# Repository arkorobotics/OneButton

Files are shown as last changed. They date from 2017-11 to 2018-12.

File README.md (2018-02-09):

# OneButton

The OneButton is a programmable single-key USB Keyboard with RGB LED's.

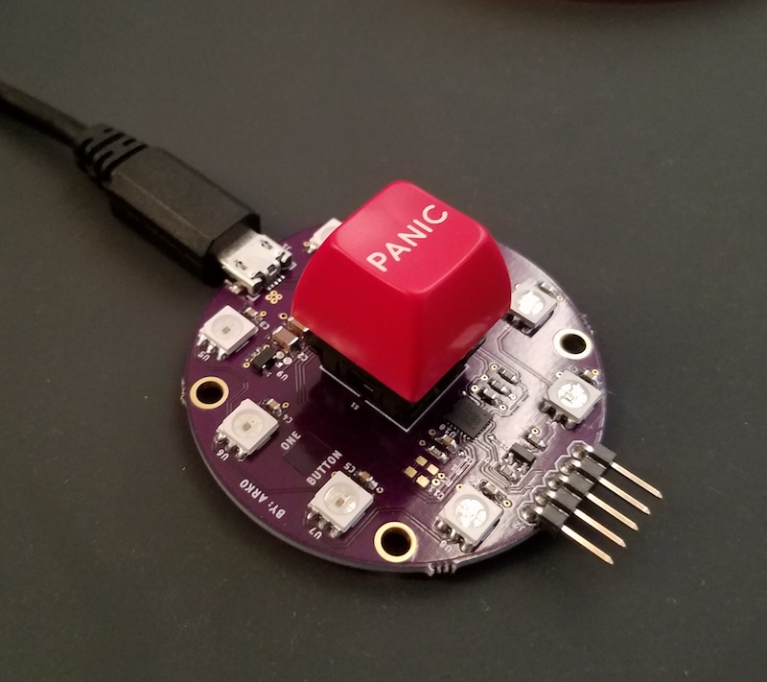
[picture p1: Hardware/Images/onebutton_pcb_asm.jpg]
onebutton Fully assmbled OneButton PCB


The OneButton serves no single purpose, but rather is designed to be programmed for multiple uses.

Possible Applications: 
- Generate pre-scripted USB keystrokes (included in the example code)
- Serve as a "Soft" E-STOP button with color LED's to indicate state
- Interface with a desktop API to perform other actions (i.e. - Indiciate a new Tweet notification by turning LED's Blue. Pressing the key opens Twitter.)
- The possiblities are not endless!

The OneButton includes six programmable RGB LED's because everyone loves blinky lights! <br>
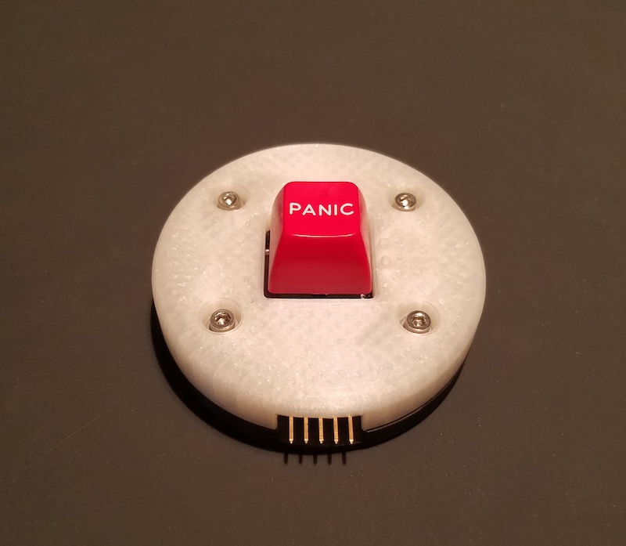
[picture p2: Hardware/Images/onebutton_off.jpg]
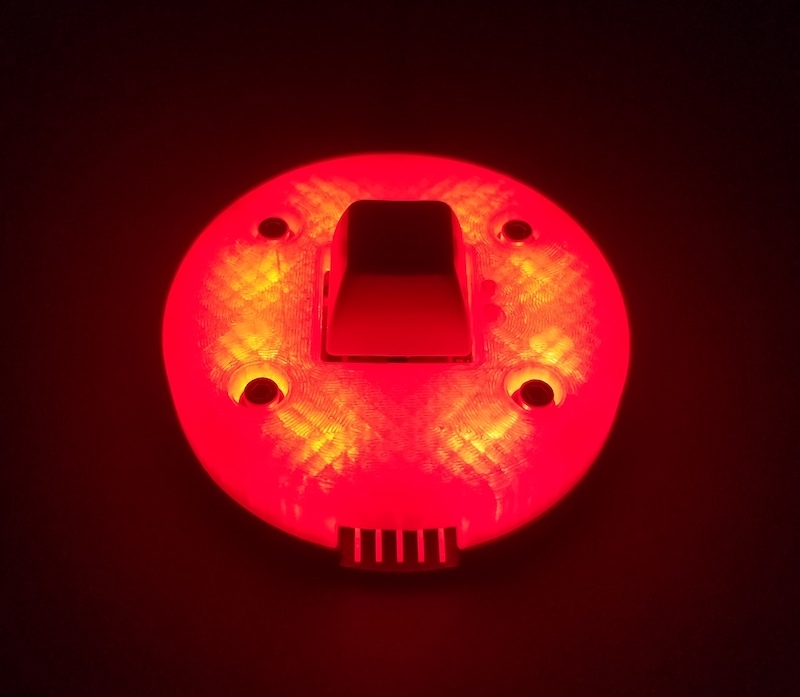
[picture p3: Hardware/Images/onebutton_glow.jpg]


...and easter eggs!<br>
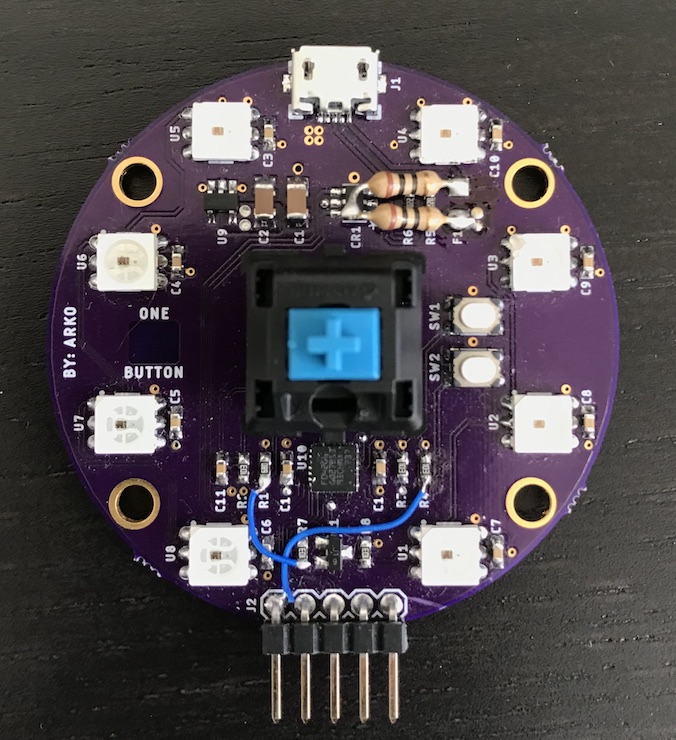
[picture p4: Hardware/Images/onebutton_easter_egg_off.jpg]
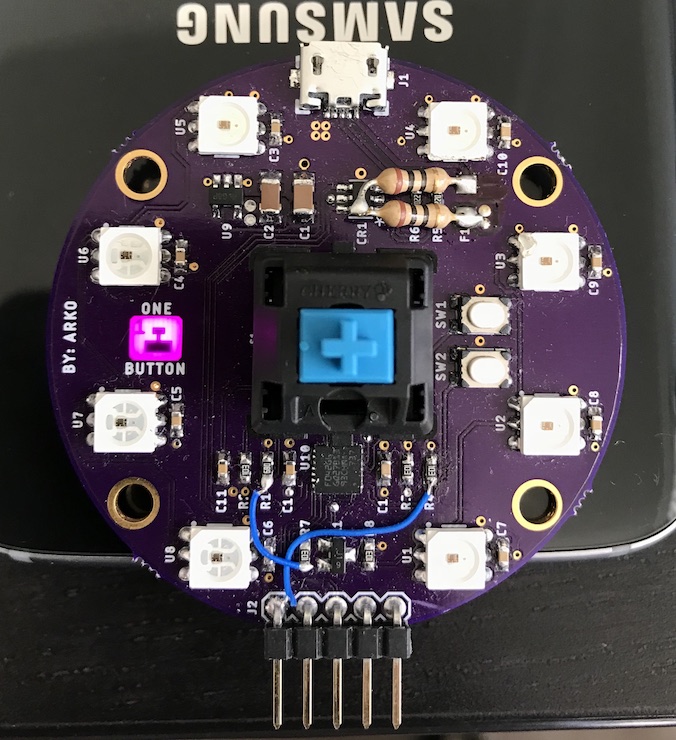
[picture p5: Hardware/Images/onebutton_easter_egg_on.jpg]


Included in this GitHub:
- Firmware: Example code written in C++ and Rust 
- Hardware: Schematic, Board, Gerber, and 3D printable enclosure CAD files

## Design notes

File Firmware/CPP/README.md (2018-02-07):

# OneButton - C++ Firmware

## Installation

1. Download and install the arm-none-eabi gcc toolchain

	https://developer.arm.com/open-source/gnu-toolchain/gnu-rm/downloads
	We recommend installing the precompiled binaries to '/usr/local'. 
	Add the bin folders (/bin & /arm-none-eabi/bin) to your environments variable 'PATH'.

2. Install STLink Tool

	https://github.com/texane/stlink

3. Install OpenOCD

	`$ brew update openocd`

4. Instal GDB Dashboard

	https://github.com/cyrus-and/gdb-dashboard

5. Install scons

	`$ brew install scons`

## Build

1. Build source using scons
	
	Optimized:

	`$ scons mode=fast mcu=f042 hsi=48000000`

	Debug:

	`$ scons mode=debug mcu=f042 hsi=48000000`

## Flash Device

1. Flash device with optimized binary using st-flash

	`$ st-flash --format ihex write src/build/fast-f042-48000000i/onebutton.hex`

## Debug using GDB

1. Build debug binary

	`$ scons mode=debug mcu=f042 hsi=48000000`

2. Open two terminal screens

3. Terminal 1: St-Util

	`$ st-util -m`

4. Terminal 2: GDB Session

	`$ arm-none-eabi-gdb src/build/debug-f042-48000000i/onebutton.elf`

	`(gdb) target extended-remote localhost:4242`

	`(gdb) load` 

	If it fails to flash, reset the device and try again.

	Reset the device manually (TODO: Fix the load/reset procedure to reset automatically after load. Uncertain if it's SW or HW issue.)

	`(gdb) continue`

## Debug using GDB Py with GDB Dashboard

1. Build debug binary

	`$ scons mode=debug mcu=f042 hsi=48000000`

2. Open three terminal screens

3. Terminal 1: St-Util

	`$ st-util -m`

4. Terminal 2: GDB Dashboard Output

	`$ tty` 

	Note the tty session. We will use this in the following steps. (i.e. "/dev/ttys001")

5. Terminal 3: GDB Py Session

	`$ cd OneButton/Firmware/CPP`

	`$ arm-none-eabi-gdb-py src/build/debug-f042-48000000i/onebutton.elf`

	`>>> dashboard -output /dev/ttys001`

	`>>> target extended-remote localhost:4242`

	`>>> load`

	If it fails to flash, reset the device and try again.

	Reset the device manually

	`>>> continue`

	`>>> continue`

6. To load new firmware after a new build

	`>>> load`

	Reset the device manually

	`>>> continue`

	`>>> continue`

7. To recover after a segfault

	`>>> kill`

	`>>> load`

	`>>> target extended-remote localhost:4242`

	`>>> continue`

	`>>> continue`

8. To exit gracefully

	`>>> kill`

	`>>> quit`

## Check for USB HID Devices

`$ system_profiler SPUSBDataType`

## Credits

Base library:  https://github.com/andysworkshop/stm32plus

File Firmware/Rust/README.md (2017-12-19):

# OneButton - Rust Firmware

## Installation

1. Download and install the arm-none-eabi gcc toolchain

https://developer.arm.com/open-source/gnu-toolchain/gnu-rm/downloads
We recommend installing the precompiled binaries to '/usr/local'. 
Add the bin folders (/bin & /arm-none-eabi/bin) to your environments variable 'PATH'.

2. Install STLink Tool

https://github.com/texane/stlink

3. Install OpenOCD

`$ brew update openocd`

4. Install Rust

`$ curl https://sh.rustup.rs -sSf | sh`

5. Install xargo

`$ cargo install xargo`

6. Set toolchain to default nightly build

`$rustup default nightly`

7. Install Rust Sources

`$ rustup component add rust-src`

## Build

1. Build command

`$ xargo build --release`

## Flash

1. Generate Hex File
`arm-none-eabi-objcopy -O ihex target/thumbv6m-none-eabi/release/onebutton onebutton.ihex`

2. Flash command
`st-flash --format ihex write onebutton.ihex`

## Credits

Base toolchain:  https://github.com/therealprof/stm32f042

USB HID Library: https://github.com/Determinant/bluepill-momo2

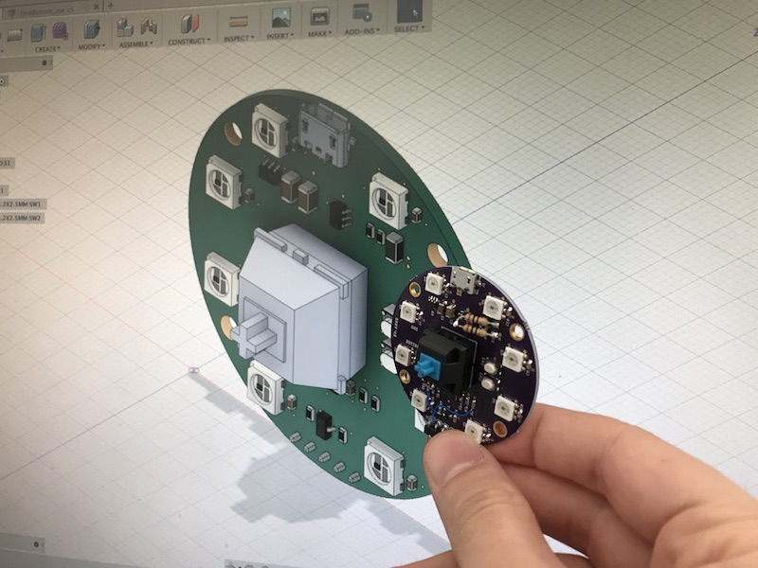
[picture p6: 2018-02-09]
Hardware/Images/onebutton_cad_vs_irl.jpg

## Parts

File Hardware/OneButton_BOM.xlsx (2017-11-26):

Qty | Value | Device | Package | Parts | Description | MPN | Cost | Link
1 |  | CONN_05 | 1X05 | J2 | Multi connection point. Often used as Generic Header-pin footprint for 0.1 inch spaced/style header connections | 61300511121 | 0.25 | https://www.digikey.com/product-detail/en/wurth-electronics-inc/61300511121/732-5318-ND/4846831
1 |  | PTCFUSE-1206 | R1206 | F1 | PTC fuses, resettable thermistors | 0ZCG0075FF2C | 0.13 | https://www.digikey.com/product-detail/en/bel-fuse-inc/0ZCG0075FF2C/507-1763-1-ND/4156150
1 |  | USB_AB_SMT | USB-AB-MICRO-SMD | J1 | USB Type AB Micro Connector | 10118192-0001LF | 0.46 | https://www.digikey.com/product-detail/en/amphenol-fci/10118192-0001LF/609-4613-1-ND/2785378
10 | 0.1uF | 0.1UFCAP-0603 | CAP-0603 | C3, C4, C5, C6, C7, C8, C9, C10, C14, C15 | 0.1µF ceramic capacitors | C0603C104K8RACTU | 0.029 | https://www.digikey.com/product-detail/en/kemet/C0603C104K8RACTU/399-1095-1-ND/411370
4 | 10k | RESISTORRES-0603 | RESC0603_N | R3, R4, R7, R8 | Generic Resistor Package | RC0603JR-0710KL | 0.044 | https://www.digikey.com/product-detail/en/yageo/RC0603JR-0710KL/311-10KGRCT-ND/729647
1 | 10uF | 10UFCAP-1206 | CAP-1206 | C1 | 10.0µF ceramic capacitors | CL31B106KAHNNNE | 0.26 | https://www.digikey.com/product-detail/en/samsung-electro-mechanics/CL31B106KAHNNNE/1276-1804-1-ND/3889890
2 | 22R | RESISTORRES-0603 | RESC0603_N | R5, R6 | Generic Resistor Package | RC0603JR-0722RL | 0.022 | https://www.digikey.com/product-detail/en/yageo/RC0603JR-0722RL/311-22GRCT-ND/729690
1 | 3.3V | V_REG_AP2112K-3.3V | SOT23-5 | U9 | AP2112 - 600mA CMOS LDO Regulator w/ Enable | AP2112K-3.3TRG1 | 0.48 | https://www.digikey.com/product-detail/en/diodes-incorporated/AP2112K-3.3TRG1/AP2112K-3.3TRG1DICT-ND/4505257
1 | 4.7uF | 4.7UFCAP-1206 | CAP-1206 | C2 | 4.7µF ceramic capacitors | C3216X7R1C475K160AB | 0.27 | https://www.digikey.com/product-detail/en/tdk-corporation/C3216X7R1C475K160AB/445-1385-1-ND/567617
1 | 68R | RESISTORRES-0603 | RESC0603_N | R1 | Generic Resistor Package | RC0603JR-0768RL | 0.1 | https://www.digikey.com/product-detail/en/yageo/RC0603JR-0768RL/311-68GRCT-ND/729768
1 | BSS138W-7-F | SMD-MOSFET-N-CH-50V-200MA-BSS138W-7-F(SOT-23) | SOT-23 | Q1 | SMD-MOSFET-N-CH | BSS138LT1G | 0.29 | https://www.digikey.com/product-detail/en/on-semiconductor/BSS138LT1G/BSS138LT1GOSCT-ND/917858
2 | DHT-4235A | SMD-BUTTON-TOP-DHT-4235A(4P-4.2X3.2MM) | SW4-SMD-4.2X3.2X2.5MM | SW1, SW2 | 311020045 | PTS810 SJK 250 SMTR LFS | 0.56 | https://www.digikey.com/product-detail/en/c-k/PTS810-SJK-250-SMTR-LFS/CKN10503CT-ND/4176675
1 | DNP | CAPACITORCAP-0603 | CAP-0603 | C11 | Generic chip capacitor | - | - | -
1 | DNP | RESISTORRES-0603 | RESC0603_N | R2 | Generic Resistor Package | - | - | -
1 | MOMENTARY-SWITCH-SPST-LED-PTH-CHERRY | MOMENTARY-SWITCH-SPST-LED-PTH-CHERRY | CHERRY-MX-LED | S1 | Momentary Switch (Pushbutton) - SPST - w/ LED | MX1A-E1NW | 0.9 | https://www.digikey.com/product-detail/en/cherry-americas-llc/MX1A-E1NW/CH197-ND/20180
1 | STM32F042GU | STM32F042GU | UFQFPN28 | U10 |  | STM32F042G6U6 | 2.45 | https://www.digikey.com/product-detail/en/stmicroelectronics/STM32F042G6U6/497-17345-ND/5268192
1 | USBLC6-2SC6SOT23-6L-M | USBLC6-2SC6SOT23-6L-M | SOT23-6L-M | CR1 |  | USBLC62SC6 | 0.42 | https://www.digikey.com/product-detail/en/stmicroelectronics/USBLC6-2SC6/497-5235-1-ND/1121688
8 | WS2812 | WS2812";LED-TRICOLOR-5050-IC" |  | U1, U2, U3, U4, U5, U6, U7, U8 | WS2812 RGB LED w/ WS2811 driver | WS2812 | 0.5 | https://www.sparkfun.com/products/11821
 |  |  |  |  |  |  | 7.165

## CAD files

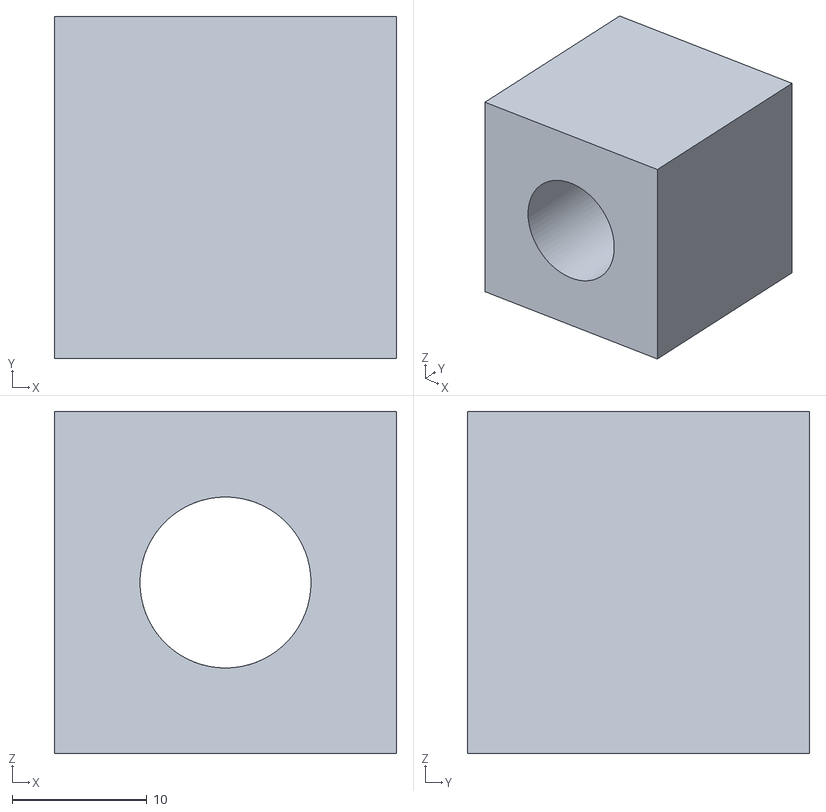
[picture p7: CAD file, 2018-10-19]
Hardware/CAD/Gourgen_Cube.stl
25.4 x 25.4 x 25.4

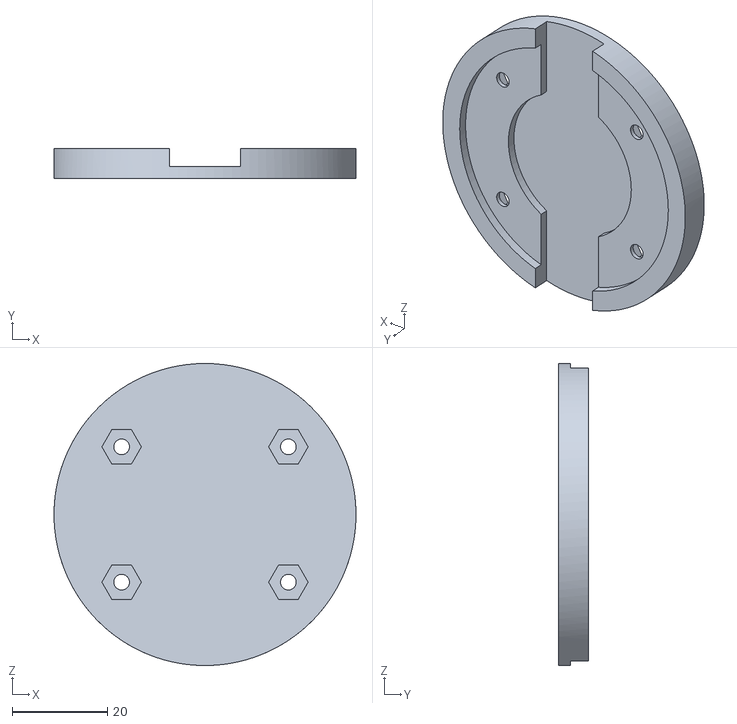
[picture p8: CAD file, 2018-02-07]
Hardware/CAD/OneButtonCase_Bottom v15.stl
63.5 x 6.35 x 63.5

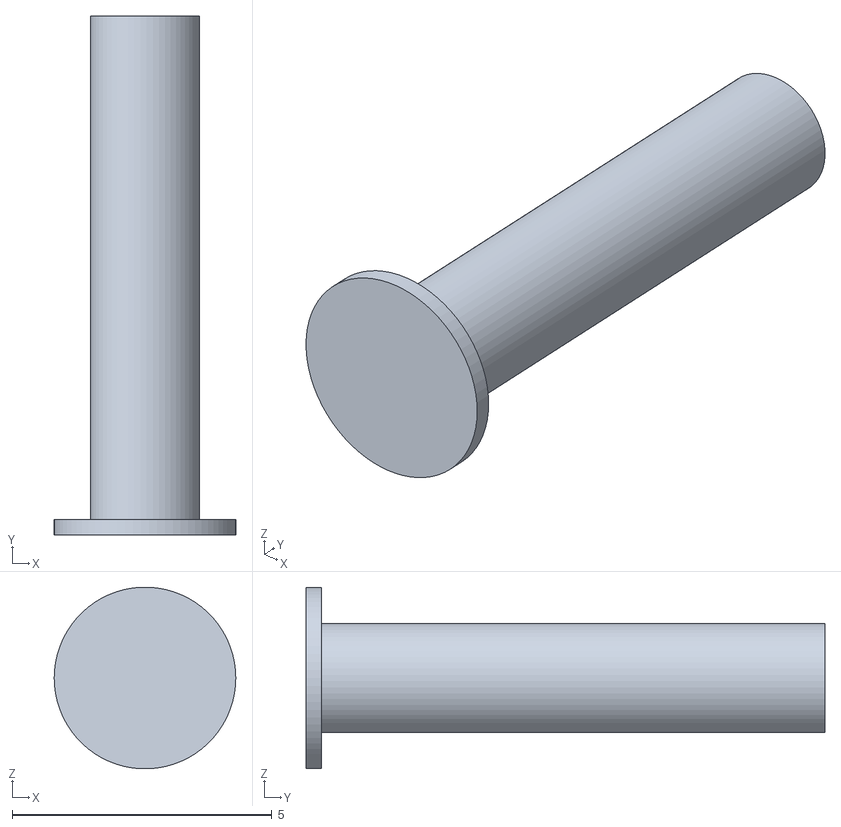
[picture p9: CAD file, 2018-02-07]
Hardware/CAD/OneButton_Reset_Boot_Button_v9.stl
3.50 x 10.0 x 3.50

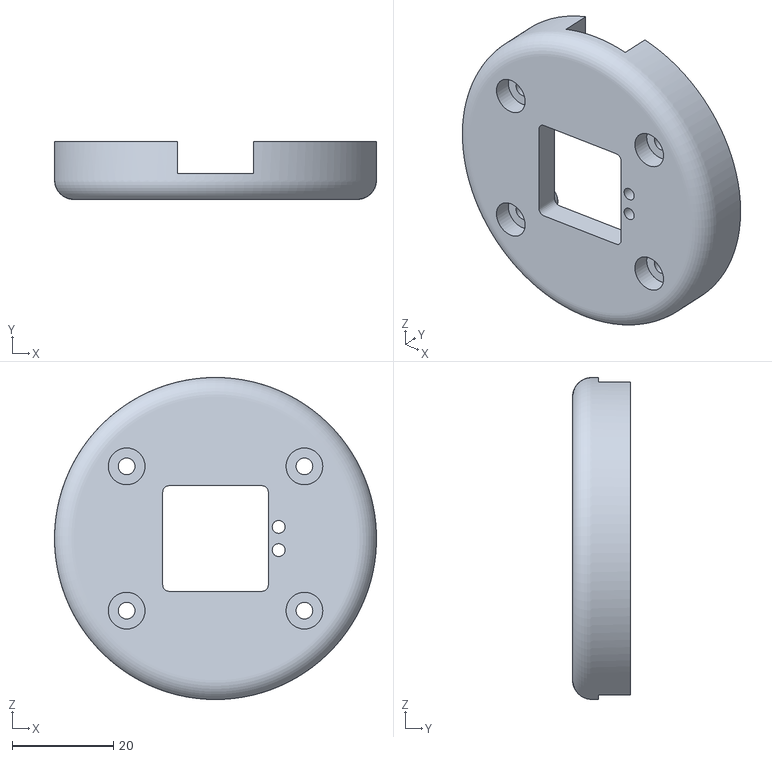
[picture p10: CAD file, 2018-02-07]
Hardware/CAD/OneButtonCase_Top v19.stl
63.5 x 11.4 x 63.5

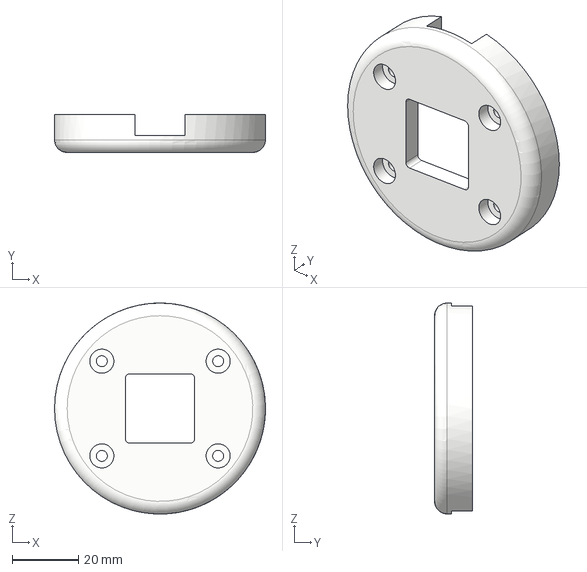
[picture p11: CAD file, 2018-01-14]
Hardware/CAD/OneButtonCaseTop.step
63.5 x 11.4 x 63.5 mm

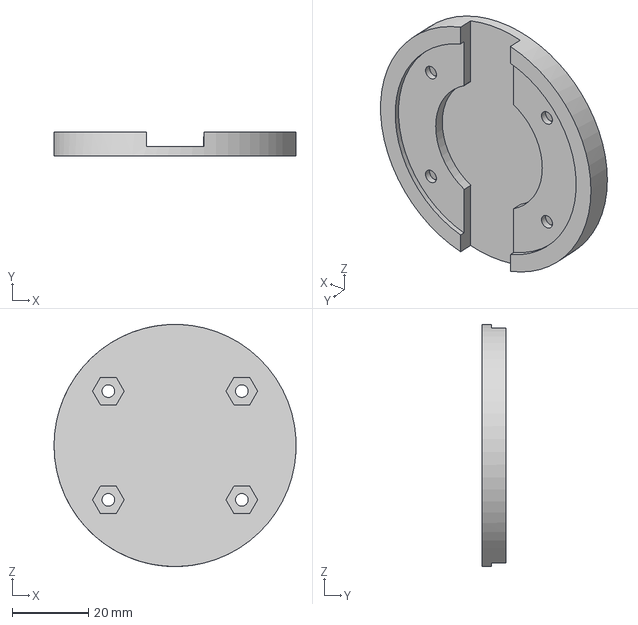
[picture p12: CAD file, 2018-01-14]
Hardware/CAD/OneButtonCaseBottom.step
63.5 x 6.35 x 63.5 mm

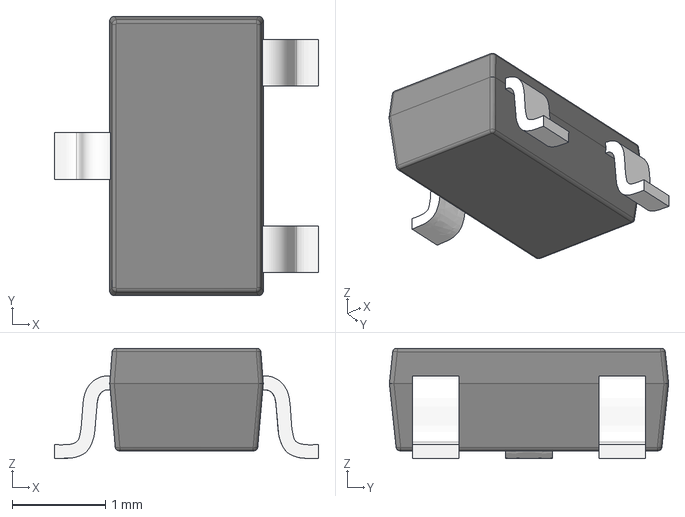
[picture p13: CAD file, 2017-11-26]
Hardware/CAD/SOT23-3.stp
2.84 x 3.00 x 1.18 mm

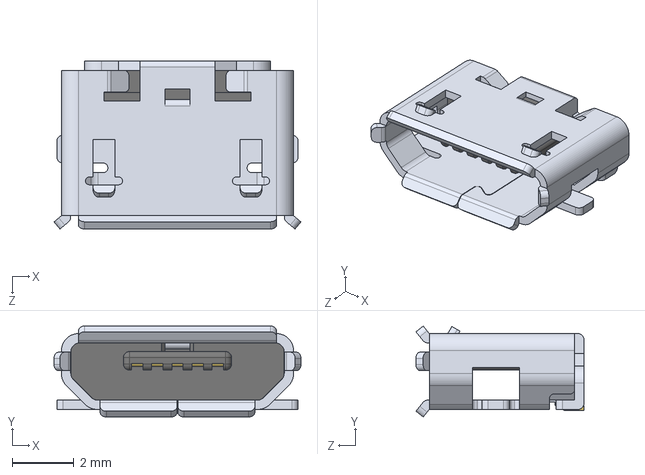
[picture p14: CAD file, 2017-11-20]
Hardware/CAD/USB_Micro.STEP
7.98 x 2.94 x 5.43 mm

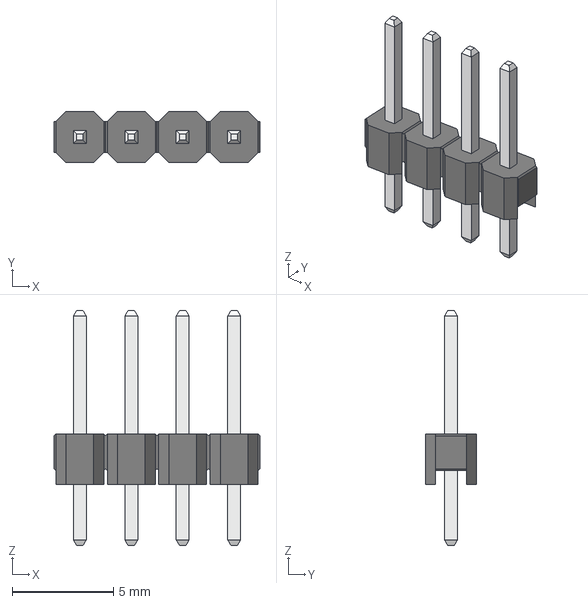
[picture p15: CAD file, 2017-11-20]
Hardware/CAD/DS1021-1x4S61.stp
10.2 x 2.54 x 11.6 mm

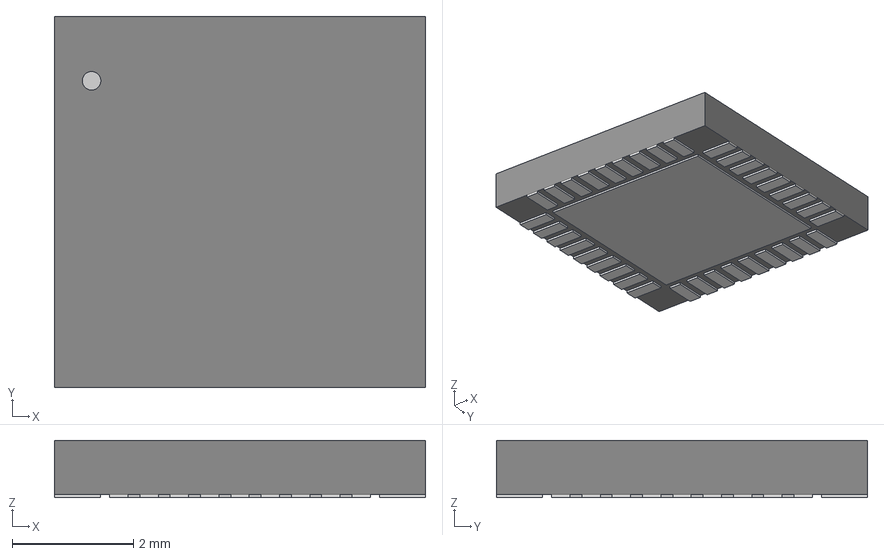
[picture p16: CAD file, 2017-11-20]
Hardware/CAD/VFQFPN-36.step
6.12 x 6.12 x 0.942 mm

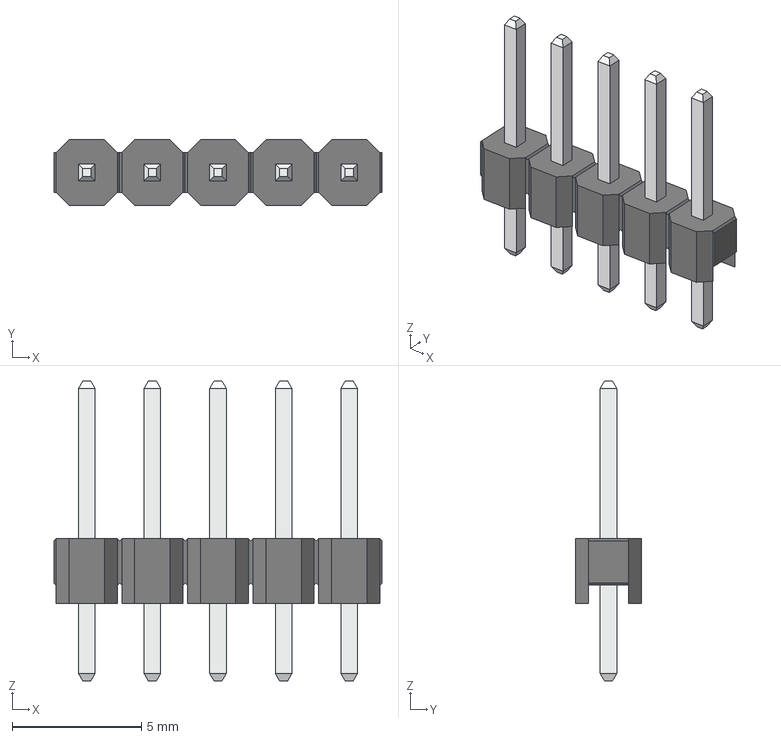
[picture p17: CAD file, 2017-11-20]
Hardware/CAD/DS1021-1x5S61.stp
12.7 x 2.54 x 11.6 mm

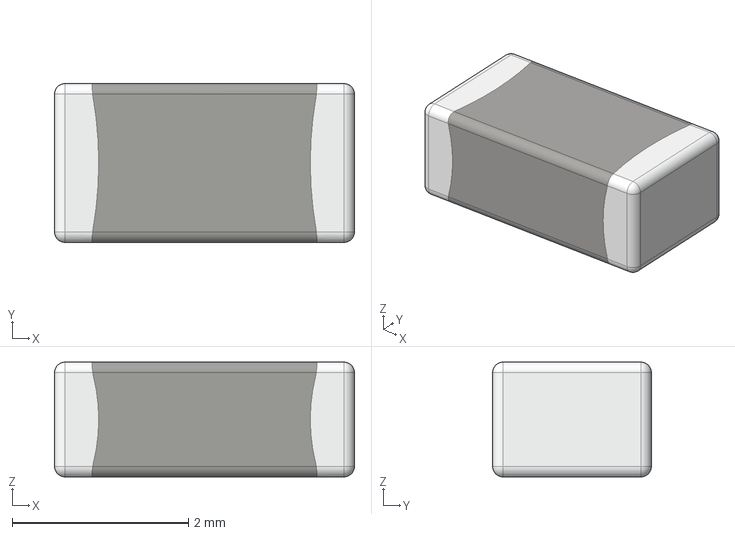
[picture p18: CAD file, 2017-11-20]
Hardware/CAD/NTC-1206-T1.3.stp
3.40 x 1.80 x 1.30 mm

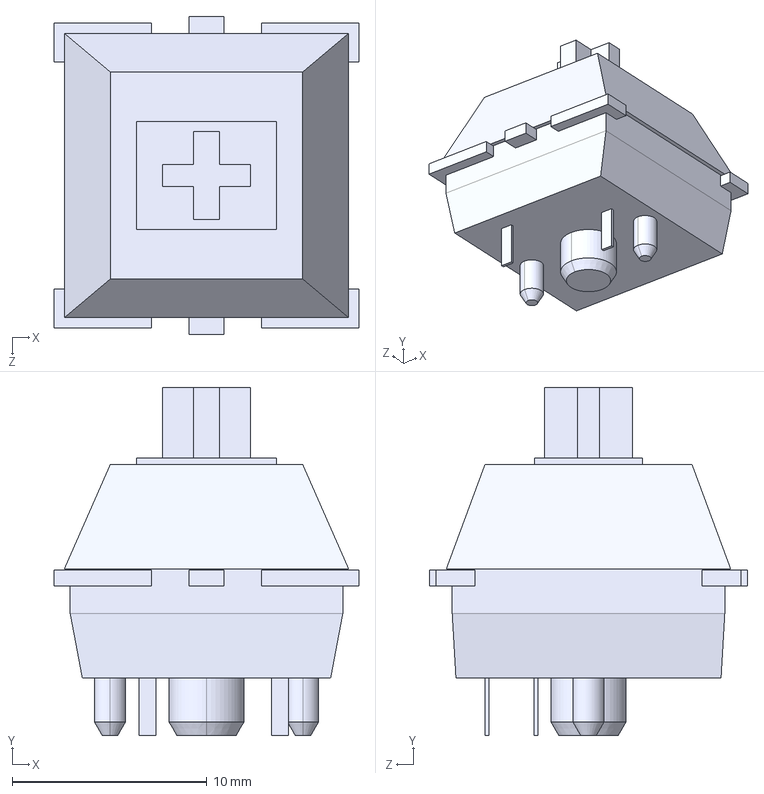
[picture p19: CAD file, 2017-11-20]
Hardware/CAD/MX_Cherry.STEP
15.6 x 17.9 x 16.3 mm

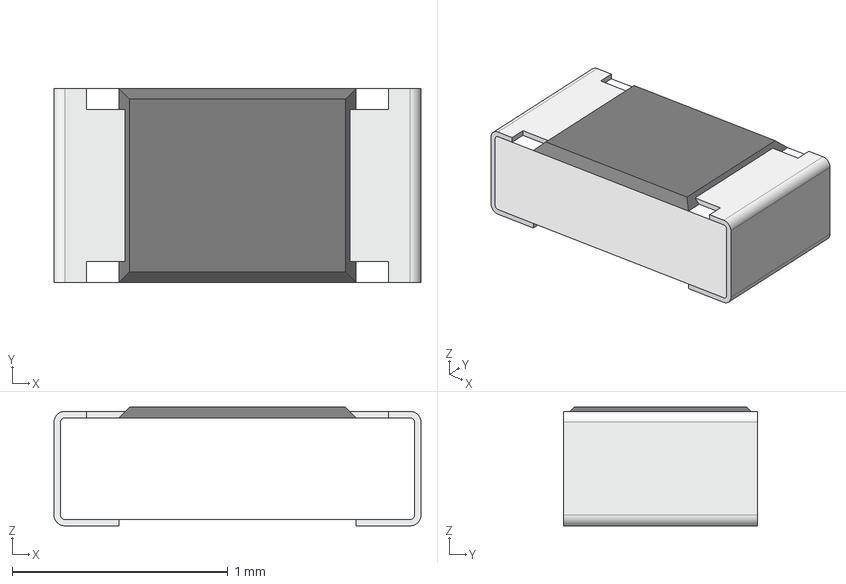
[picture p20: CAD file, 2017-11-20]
Hardware/CAD/RESC-0603.stp
1.70 x 0.9 x 0.55 mm

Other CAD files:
Hardware/CAD/CAPC-0603-T0.9-BN.stp
Hardware/CAD/MO-178AA.stp
Hardware/CAD/CAPC-1210-T1.8-BN.stp
Hardware/CAD/SOT223.STEP
Hardware/CAD/CAPC-1206-T1.8-BN.stp
Hardware/CAD/Crystal.STEP
Hardware/CAD/OneButtonCase_Bottom_v11.stl
Hardware/CAD/OneButtonCase_Top v10.stl
Hardware/CAD/OneButtonCase_Top_v8.stl
Hardware/CAD/OneButton_Reset_Boot_Button v7.stl
Hardware/CAD/SC-76.stp
Hardware/CAD/Tact_Switch.STEP
Hardware/CAD/UFQFPN28.STEP
Hardware/CAD/WS2812.stp

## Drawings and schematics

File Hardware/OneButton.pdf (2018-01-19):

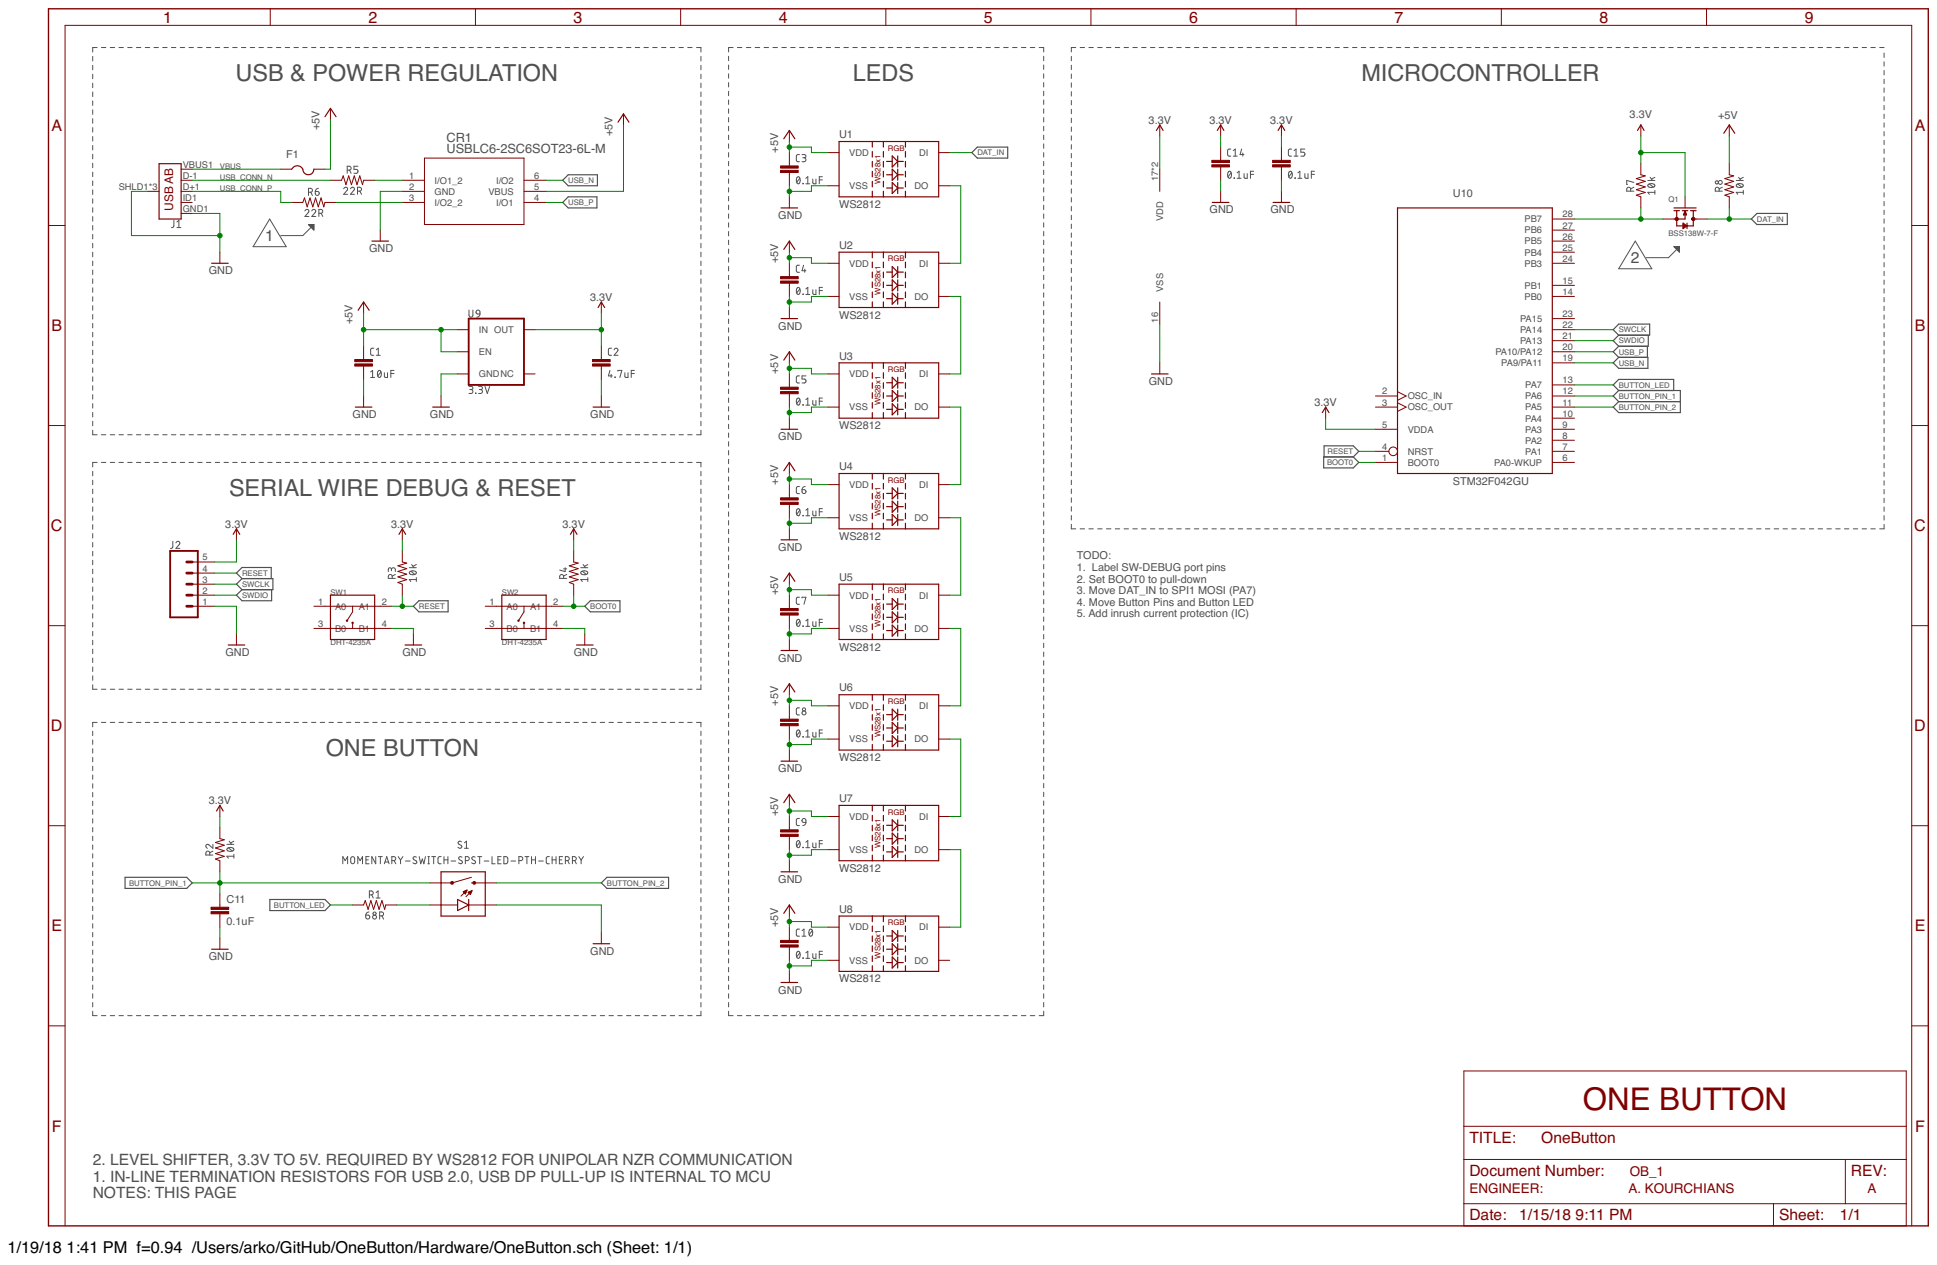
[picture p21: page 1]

SERIAL WIRE DEBUG & RESET

TODO: 1. Label SW-DEBUG port pins 2. Set BOOT0 to pull-down

3. Move DAT_IN to SPI1 MOSI (PA7)
4. Move Button Pins and Button LED
5. Add inrush current protection (IC)

2. LEVEL SHIFTER, 3.3V TO 5V. REQUIRED BY WS2812 FOR UNIPOLAR NZR COMMUNICATION
1. IN-LINE TERMINATION RESISTORS FOR USB 2.0, USB DP PULL-UP IS INTERNAL TO MCU
NOTES: THIS PAGE

Document Number: OB_1 ENGINEER: A. KOURCHIANS | REV: A

Date: 1/15/18 9:11 PM | Sheet: 1/1

1/19/18 1:41 PM f=0.94 /Users/arko/GitHub/OneButton/Hardware/OneButton.sch (Sheet: 1/1)

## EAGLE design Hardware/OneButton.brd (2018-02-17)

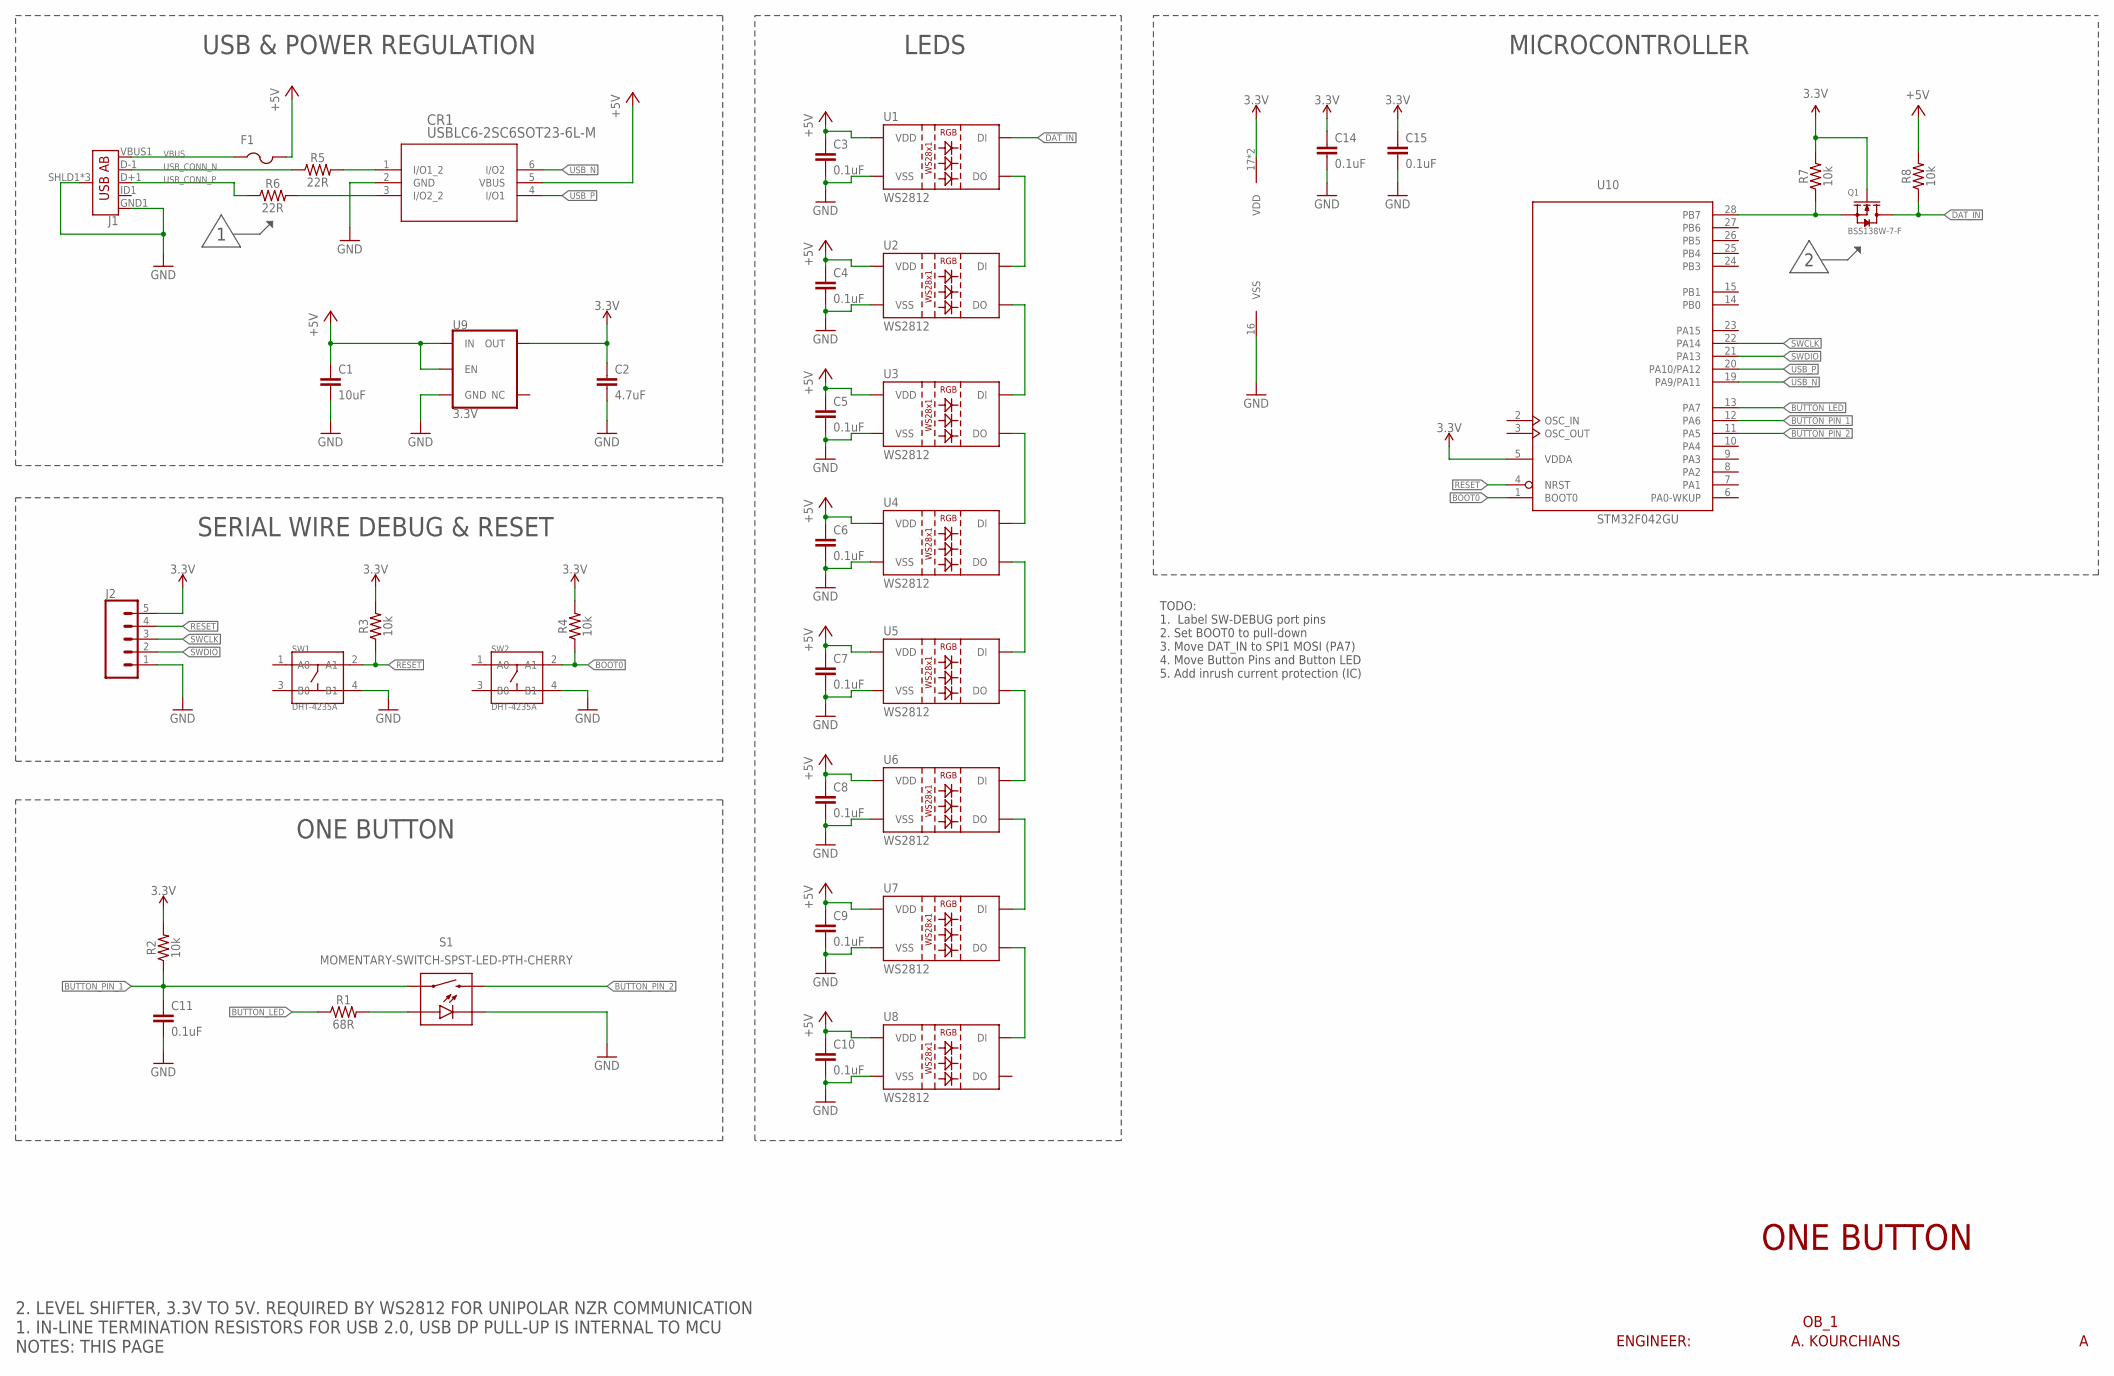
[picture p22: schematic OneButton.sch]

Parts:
C1: 10uF; CAP-1206
C2: 4.7uF; CAP-1206
C3, C4, C5, C6, C7, C8, C9, C10, C11, C14, C15: 0.1uF; CAP-0603
CR1: USBLC6-2SC6SOT23-6L-M; SOT23-6L-M
F1: PTCFUSE-1206; R1206
J1: USB_AB_SMT; USB-AB-MICRO-SMD
J2: CONN_05; 1X05
Q1: BSS138W-7-F; SOT-23
R1: 68R; RESC0603_N
R2, R3, R4, R7, R8: 10k; RESC0603_N
R5, R6: 22R; RESC0603_N
S1: MOMENTARY-SWITCH-SPST-LED-PTH-CHERRY; CHERRY-MX-LED
SW1, SW2: DHT-4235A; SW4-SMD-4.2X3.2X2.5MM
U1, U2, U3, U4, U5, U6, U7, U8: WS2812; LED-TRICOLOR-5050-IC
U9: 3.3V; SOT23-5
U10: STM32F042GU; UFQFPN28

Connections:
3.3V: C2.1, C14.1, C15.1, J2.5, Q1.1 (G), R2.2, R3.2, R4.2, R7.2, U9.5 (OUT), U10.5 (VDDA), U10.17 (VDD), U10.18 (VDD)
+5V: C1.1, C3.1, C4.1, C5.1, C6.1, C7.1, C8.1, C9.1, C10.1, CR1.5 (VBUS), F1.2, R8.2, U1.3 (VDD), U1.5 (VDD), U2.3 (VDD), U2.5 (VDD), U3.3 (VDD), U3.5 (VDD), U4.3 (VDD), U4.5 (VDD), U5.3 (VDD), U5.5 (VDD), U6.3 (VDD), U6.5 (VDD), U7.3 (VDD), U7.5 (VDD), U8.3 (VDD), U8.5 (VDD), U9.1 (IN), U9.3 (EN)
BOOT0: R4.1, SW2.2 (A1), U10.1 (BOOT0)
BUTTON_LED: R1.1, U10.13 (PA7)
BUTTON_PIN_1: C11.1, R2.1, S1.S1 (1), U10.12 (PA6)
BUTTON_PIN_2: S1.S2 (2), U10.11 (PA5)
DAT_IN: Q1.3 (D), R8.1, U1.2 (DI)
GND: C1.2, C2.2, C3.2, C4.2, C5.2, C6.2, C7.2, C8.2, C9.2, C10.2, C11.2, C14.2, C15.2, CR1.2 (GND), J1.GND1 (GND), J1.SHLD1 (SHIELD), J1.SHLD2 (SHIELD), J1.SHLD3 (SHIELD), J2.1, S1.K (C), S1.K1 (C), SW1.4 (B1), SW2.4 (B1), U1.6 (VSS), U2.6 (VSS), U3.6 (VSS), U4.6 (VSS), U5.6 (VSS), U6.6 (VSS), U7.6 (VSS), U8.6 (VSS), U9.2 (GND), U10.16 (VSS)
unnamed: Q1.2 (S), R7.1, U10.28 (PB7)
unnamed: R1.2, S1.A, S1.A1 (A)
unnamed: U1.1 (DO), U2.2 (DI)
unnamed: U2.1 (DO), U3.2 (DI)
unnamed: U3.1 (DO), U4.2 (DI)
unnamed: U4.1 (DO), U5.2 (DI)
unnamed: U5.1 (DO), U6.2 (DI)
unnamed: U6.1 (DO), U7.2 (DI)
unnamed: U7.1 (DO), U8.2 (DI)
RESET: J2.4, R3.1, SW1.2 (A1), U10.4 (NRST)
SWCLK: J2.3, U10.22 (PA14)
SWDIO: J2.2, U10.21 (PA13)
USB_CONN_N: J1.D-1 (D-), R5.1
USB_CONN_P: J1.D+1 (D+), R6.1
USB_N: CR1.6 (I/O2), U10.19 (PA9/PA11)
USB_P: CR1.4 (I/O1), U10.20 (PA10/PA12)
USB_R_N: CR1.1 (I/O1_2), R5.2
USB_R_P: CR1.3 (I/O2_2), R6.2
VBUS: F1.1, J1.VBUS1 (VBUS)

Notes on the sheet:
ONE BUTTON
ENGINEER: A. KOURCHIANS
OB_1
USB & POWER REGULATION
SERIAL WIRE DEBUG & RESET
LEDS
MICROCONTROLLER
2. LEVEL SHIFTER, 3.3V TO 5V. REQUIRED BY WS2812 FOR UNIPOLAR NZR COMMUNICATION 1. IN-LINE TERMINATION RESISTORS FOR USB 2.0, USB DP PULL-UP IS INTERNAL TO MCU NOTES: THIS PAGE
TODO: 1. Label SW-DEBUG port pins 2. Set BOOT0 to pull-down 3. Move DAT_IN to SPI1 MOSI (PA7) 4. Move Button Pins and Button LED 5. Add inrush current protection (IC)

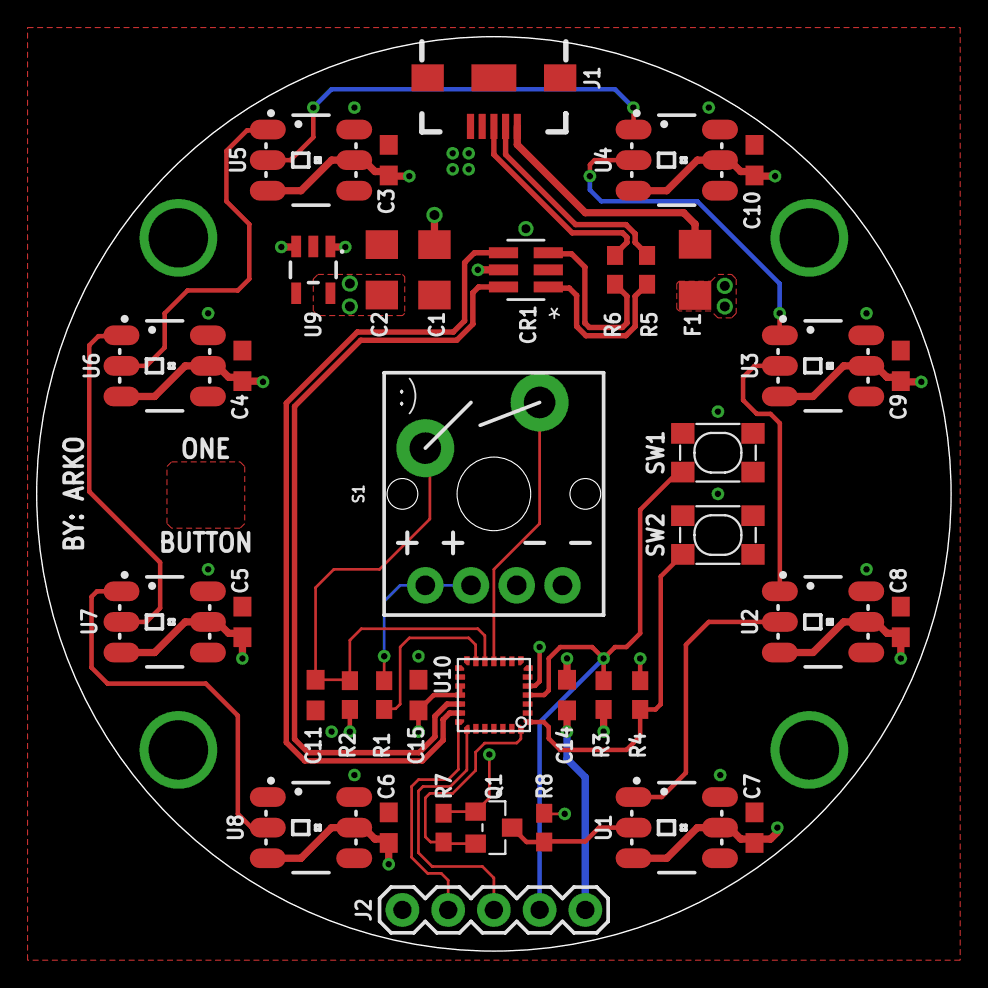
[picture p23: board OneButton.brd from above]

Board: 4 copper layers, 50.8 x 50.8 mm, 39 parts (0 on the bottom side), 27 nets.

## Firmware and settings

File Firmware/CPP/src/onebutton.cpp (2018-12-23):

/*

One Button
----------

By: Arko

Base Libraries: Andy Brown - https://github.com/andysworkshop/stm32plus

*/

#include "config/stm32plus.h"
#include "config/usb/device/device.h"
#include "config/spi.h"
#include "config/dma.h"
#include "config/timing.h"

#include "usb_hid_keys.h"


using namespace stm32plus;


class OneButton {

  protected:

    /*
     * Definition for the LED. Change to suit your board.
     */

    enum { 
      KEY_IN_PIN = 6,
      KEY_OUT_PIN = 5
    };

    typedef GpioA<DefaultDigitalInputFeature<KEY_IN_PIN>> ButtonInPort;
    typedef GpioA<DefaultDigitalOutputFeature<KEY_OUT_PIN>> ButtonOutPort;


    uint8_t led_bytes[24];

    uint8_t dataToSend[289];

    uint32_t estop = 1;

    uint8_t colorsweep = 0;

    /*
     * The constants in this structure are used to customize the HID to your
     * requirements.
     */

    struct UsbHidKeyboard {

      enum {

        /*
         * USB Vendor and Product ID. Unfortunately commercial users will probably have to pay
         * the license fee to get an official VID and 64K PIDs with it. For testing and hacking
         * you can just do some research to find an unused VID and use it as you wish.
         */

        VID = 0xCAFE,
        PID = 0x1CFB,



        IN_ENDPOINT_MAX_PACKET_SIZE = 9,   // 1 byte report id + 8-byte report
        OUT_ENDPOINT_MAX_PACKET_SIZE = 2,  // 1 byte report id + 1-byte report

        /*
         * The number of milliamps that our device will use. The maximum you can specify is 510.
         */

        MILLIAMPS = 500,

        /*
         * Additional configuration flags for the device. The available options that can be
         * or'd together are UsbConfigurationFlags::SELF_POWERED and
         * UsbConfigurationFlags::REMOTE_WAKEUP.
         */

        CONFIGURATION_FLAGS = 0,      // we want power from the bus

        /*
         * The language identifier for our strings
         */

        LANGUAGE_ID = 0x0409    // US English.
      };

      /*
       * USB devices support a number of Unicode strings that are used to show information
       * about the device such as the manufacturer, product, serial number and some other
       * stuff that's not usually as visible to the user. You need to define all 5 of them
       * here with the correct byte length. Look ahead to where these are defined to see
       * what the byte lengths will be and then come back here and set them accordingly.
       */

      static const uint8_t ManufacturerString[32];
      static const uint8_t ProductString[22];
      static const uint8_t SerialString[12];
      static const uint8_t ConfigurationString[8];
      static const uint8_t InterfaceString[8];
    };


    /*
     * Member variables
     */

    volatile bool _deviceConfigured;
    volatile uint32_t _receivedReportTime;
    volatile uint32_t _lastTransmitTime;

    volatile uint8_t _debounce = 0;

  public:
    
    /*
    * Declare the USB custom HID object. This will initialise pins but won't
    * power up the device yet.
    */

    UsbMouse<UsbHidKeyboard> usb;


    void run() {

      MillisecondTimer::delay(200);

      /*
       * Set up the default values for the member variables
       */

      _deviceConfigured=false;
      _receivedReportTime=UINT32_MAX-1000;
      _lastTransmitTime=0;


      // SPI DMA - WS8212 Single NZR Communication Mode
      //
      typedef Spi1<> SPISender;

      SPISender::Parameters senderParams;

      senderParams.spi_mode = SPI_Mode_Master;
      senderParams.spi_baudRatePrescaler = SPI_BaudRatePrescaler_4;

      SPISender sender(senderParams);

      Spi1TxDmaChannel<SpiDmaWriterFeature<Spi1PeripheralTraits,DMA_Priority_Medium> > dmaSender;


      /*
       * Declare the One Button Key port
       */

      ButtonOutPort keyout;
      keyout[KEY_OUT_PIN].reset();
      keyout.setState(0);

      ButtonInPort keyin;
      keyin[KEY_IN_PIN].reset();

      MillisecondTimer::delay(1000);



      /*
       * Subscribe to all the events
       */

      usb.UsbRxEventSender.insertSubscriber(UsbRxEventSourceSlot::bind(this,&OneButton::onReceive));
      usb.UsbTxCompleteEventSender.insertSubscriber(UsbTxCompleteEventSourceSlot::bind(this,&OneButton::onTransmitComplete));
      usb.UsbStatusEventSender.insertSubscriber(UsbStatusEventSourceSlot::bind(this,&OneButton::onStatusChange));

      /*
       * Start the peripheral. This will pull up the DP line which is the trigger for the host
       * to start enumeration of this device
       */

      usb.start();

      uint8_t wiggle = 0;

      // Main Loop
      for(;;)
      {

        if(wiggle != 0)
        {
          // Initialize USB Key Report
          uint8_t usb_key_report[8] = {0, 0, 0, 0, 0, 0, 0, 0};

          // CTRL + F12
          usb_key_report[0] = 0;
          usb_key_report[1] = 10;
          usb.sendReport(usb_key_report,sizeof(usb_key_report));
          MillisecondTimer::delay(10);

          sendendreport();

          MillisecondTimer::delay(10);

          // CTRL + F12
          usb_key_report[0] = 0;
          usb_key_report[1] = -10;
          usb.sendReport(usb_key_report,sizeof(usb_key_report));
          MillisecondTimer::delay(10);
        }

        if(keyin.read()==0 && _debounce == 0)
        {
          wiggle = ~wiggle;

          /*
          // TYPE 'firefox'
          uint8_t keystring[] = "firefox";
          sendstring(keystring, sizeof(keystring));
          MillisecondTimer::delay(20);

          // Wait for search results
          MillisecondTimer::delay(500);

          // ENTER
          usb_key_report[0] = 0;
          usb_key_report[2] = KEY_ENTER;
          usb.sendReport(usb_key_report,sizeof(usb_key_report));
          MillisecondTimer::delay(12000);
          sendendreport();

          // TYPE 'star'
          uint8_t h_string[] = "star";
          sendstring(h_string, sizeof(h_string));
          MillisecondTimer::delay(20);
          sendendreport();

          // SPACE
          usb_key_report[0] = 0;
          usb_key_report[2] = KEY_SPACE;
          usb.sendReport(usb_key_report,sizeof(usb_key_report));
          MillisecondTimer::delay(20);
          sendendreport();

          // TYPE 'wars'
          uint8_t t_string[] = "wars";
          sendstring(t_string, sizeof(t_string));
          MillisecondTimer::delay(20);
          sendendreport();

          // SPACE
          usb_key_report[0] = 0;
          usb_key_report[2] = KEY_SPACE;
          usb.sendReport(usb_key_report,sizeof(usb_key_report));
          MillisecondTimer::delay(20);
          sendendreport();

          // TYPE 'soundtrack'
          uint8_t p_string[] = "soundtrack";
          sendstring(p_string, sizeof(p_string));
          MillisecondTimer::delay(20);
          sendendreport();

          // SPACE
          usb_key_report[0] = 0;
          usb_key_report[2] = KEY_SPACE;
          usb.sendReport(usb_key_report,sizeof(usb_key_report));
          MillisecondTimer::delay(20);
          sendendreport();

          // TYPE 'marshal'
          uint8_t mar_string[] = "marshal";
          sendstring(mar_string, sizeof(mar_string));
          MillisecondTimer::delay(50);
          sendendreport();
          MillisecondTimer::delay(100);

          // TYPE 'l'
          uint8_t ll_string[] = "l";
          sendstring(ll_string, sizeof(ll_string));
          MillisecondTimer::delay(50);
          sendendreport();
          MillisecondTimer::delay(500);

          // TAB
          usb_key_report[0] = 0;
          usb_key_report[2] = KEY_TAB;
          usb.sendReport(usb_key_report,sizeof(usb_key_report));
          MillisecondTimer::delay(20);
          sendendreport();
          MillisecondTimer::delay(500);

          // TAB
          usb_key_report[0] = 0;
          usb_key_report[2] = KEY_TAB;
          usb.sendReport(usb_key_report,sizeof(usb_key_report));
          MillisecondTimer::delay(20);
          sendendreport();
          MillisecondTimer::delay(500);


          // ENTER
          usb_key_report[0] = 0;
          usb_key_report[2] = KEY_ENTER;
          usb.sendReport(usb_key_report,sizeof(usb_key_report));
          MillisecondTimer::delay(50);
          sendendreport();
          MillisecondTimer::delay(1000);

          // -----------------

          // CTRL + F12
          usb_key_report[0] = KEY_MOD_LCTRL;
          usb_key_report[2] = KEY_F12;
          usb.sendReport(usb_key_report,sizeof(usb_key_report));
          MillisecondTimer::delay(20);
          
          // Wait for search box
          MillisecondTimer::delay(500);

          // TYPE 'terminal'
          uint8_t ter_string[] = "terminal";
          sendstring(ter_string, sizeof(ter_string));
          MillisecondTimer::delay(20);
          sendendreport();
          // Wait for search results
          MillisecondTimer::delay(1500);

          // ENTER
          usb_key_report[0] = 0;
          usb_key_report[2] = KEY_ENTER;
          usb.sendReport(usb_key_report,sizeof(usb_key_report));
          MillisecondTimer::delay(20);
          sendendreport();
          MillisecondTimer::delay(2500);

          // TYPE 'telnet'
          uint8_t tel_string[] = "telnet";
          sendstring(tel_string, sizeof(tel_string));
          MillisecondTimer::delay(20);
          sendendreport();

          // SPACE
          usb_key_report[0] = 0;
          usb_key_report[2] = KEY_SPACE;
          usb.sendReport(usb_key_report,sizeof(usb_key_report));
          MillisecondTimer::delay(20);
          sendendreport();

          // TYPE 'towel'
          uint8_t towel_string[] = "towel";
          sendstring(towel_string, sizeof(towel_string));
          MillisecondTimer::delay(20);
          sendendreport();

          // DOT
          usb_key_report[0] = 0;
          usb_key_report[2] = KEY_DOT;
          usb.sendReport(usb_key_report,sizeof(usb_key_report));
          MillisecondTimer::delay(20);
          sendendreport();

          // TYPE 'blinkenlights'
          uint8_t blink_string[] = "blinkenlights";
          sendstring(blink_string, sizeof(blink_string));
          MillisecondTimer::delay(20);
          sendendreport();

          // DOT
          usb_key_report[0] = 0;
          usb_key_report[2] = KEY_DOT;
          usb.sendReport(usb_key_report,sizeof(usb_key_report));
          MillisecondTimer::delay(20);
          sendendreport();

          // TYPE 'nl'
          uint8_t nl_string[] = "nl";
          sendstring(nl_string, sizeof(nl_string));
          MillisecondTimer::delay(20);
          sendendreport();

          // ENTER
          usb_key_report[0] = 0;
          usb_key_report[2] = KEY_ENTER;
          usb.sendReport(usb_key_report,sizeof(usb_key_report));
          MillisecondTimer::delay(20);
          sendendreport();
          MillisecondTimer::delay(500);
          */

          //0xF00 - High
          //0xFC0 - Low

          uint32_t led_bytes_idx = 0;
          uint32_t color_g = wiggle;
          uint32_t color_r = ~wiggle;
          uint32_t color_b = 0;

          for(led_bytes_idx = 0; led_bytes_idx < 24; led_bytes_idx++)
          {
            if(led_bytes_idx % 3 == 0)
            {
              led_bytes[led_bytes_idx] = color_g;
            }
            if(led_bytes_idx % 3 == 1)
            {
              led_bytes[led_bytes_idx] = color_r;
            }
            if(led_bytes_idx % 3 == 2)
            {
              led_bytes[led_bytes_idx] = color_b;
            }
          }
          
          colorsweep++;
          
          uint16_t led_bit_high = 0xFE0;
          uint16_t led_bit_low = 0xF00;

          uint16_t led_bit_1 = 0;
          uint16_t led_bit_2 = 0;

          uint32_t data_idx = 0;

          for(int a=0; a<24; a++)
          {
            uint8_t led_byte = led_bytes[a];

            for(int b=0; b<8; b=b+2)
            {
              if( ((led_byte >> b) & 0x01) == 1)
              {
                led_bit_1 = led_bit_high;
              }
              else
              {
                led_bit_1 = led_bit_low;
              }

              if( ((led_byte >> (b+1)) & 0x01) == 1)
              {
                led_bit_2 = led_bit_high;
              }
              else
              {
                led_bit_2 = led_bit_low;
              }

              dataToSend[data_idx]   = (uint8_t)(0xFF & (uint16_t)(led_bit_1 >> 4));
              dataToSend[data_idx+1] = ((uint8_t)(0x0F & led_bit_1) << 4) | (uint8_t)(0x0F & (uint16_t)(led_bit_2 >> 8));
              dataToSend[data_idx+2] = (uint8_t)(0xFF & (uint16_t)(led_bit_2));

              data_idx = data_idx + 3;
            }
          }

          dataToSend[288] = 0;

          // SPI DMA Output to WS8212
          sender.setNss(false);

          dmaSender.beginWrite(dataToSend,sizeof(dataToSend));

          _debounce = 1;

          MillisecondTimer::delay(200);

        }
        else
        {
          // SPI DMA Output to WS8212
          sender.setNss(false);

          dmaSender.beginWrite(dataToSend,sizeof(dataToSend));
        }

        if(keyin.read() == 1)
        {
          _debounce = 0;
        }

        sender.waitForIdle();
        sender.setNss(true);

        MillisecondTimer::delay(1);

      }

    }


    /*
     * Data received from the host
     */

    void onReceive(uint8_t endpointIndex,const uint16_t *data,uint16_t size) {

      // note that the report data is always prefixed with the report id, which is
      // 0x02 in the stm32plus custom HID implementation for reports OUT from the host

      if(endpointIndex==1 && size==2 && memcmp(data,"\x02\x01",size)==0)
        _receivedReportTime=MillisecondTimer::millis();
    }


    /*
     * Finished sending data to the host
     */

    void onTransmitComplete(uint8_t /* endpointIndex */,uint16_t /* size */) {
      // ACK received from the host
    }


    /*
     * Device status change event
     */

    void onStatusChange(UsbStatusType newStatus) {

      switch(newStatus) {

        case UsbStatusType::STATE_CONFIGURED:
        _deviceConfigured=true;
        _lastTransmitTime=MillisecondTimer::millis()+5000;    // 5 second delay before starting to send
        break;

        case UsbStatusType::STATE_DEFAULT:
        case UsbStatusType::STATE_ADDRESSED:
        case UsbStatusType::STATE_SUSPENDED:
          _deviceConfigured=false;
          break;

        default:
          break;
      }
    }

    uint8_t reverseBits(uint8_t byte_in)
    {
      uint8_t byte = byte_in;
      uint8_t byte_out = 0;
      uint8_t bit = 0;

      for(int idx=1; idx<=8; idx++)
      { 
        bit = byte & 0x01;
        byte = byte >> 1;
        byte_out = byte_out << 1; 
        if(bit==1)
        {
          byte_out = byte_out + 1;
        }
      }

      return byte_out;
    }


    void sendstring(uint8_t* straddress, uint8_t length)
    {
      for(uint8_t i=0; i < length; i++)
      {
        uint8_t _sendchar = straddress[i] - (uint8_t)(0x5D);

        // Send Key Hit
        uint8_t usb_report[8] = {0, 0, _sendchar, 0, 0, 0, 0, 0};

        usb.sendReport(usb_report,sizeof(usb_report));

        MillisecondTimer::delay(20);
      }
    }

    void sendendreport()
    {
      // Last Key Report must be all zeros
      uint8_t usb_end_report[8] = {0, 0, 0, 0, 0, 0, 0, 0};
      usb.sendReport(usb_end_report,sizeof(usb_end_report));
      MillisecondTimer::delay(20);
    }
};


/*
 * These are the USB device strings in the format required for a USB string descriptor.
 * To change these to suit your device you need only change the unicode string in the
 * last line of each definition to suit your device. Then count up the bytes required for
 * the complete descriptor and go back and insert that byte count in the array declaration
 * in the configuration class.
 */

const uint8_t OneButton::UsbHidKeyboard::ManufacturerString[sizeof(OneButton::UsbHidKeyboard::ManufacturerString)]={
  sizeof(OneButton::UsbHidKeyboard::ManufacturerString),
  USB_DESC_TYPE_STRING,
  'O',0,'N',0,'E',0,' ',0,'B',0,'U',0,'T',0,'T',0,'O',0,'N',0
};

const uint8_t OneButton::UsbHidKeyboard::ProductString[sizeof(OneButton::UsbHidKeyboard::ProductString)]={
  sizeof(OneButton::UsbHidKeyboard::ProductString),
  USB_DESC_TYPE_STRING,
  'O',0,'N',0,'E',0,' ',0,'B',0,'U',0,'T',0,'T',0,'O',0,'N',0
};

const uint8_t OneButton::UsbHidKeyboard::SerialString[sizeof(OneButton::UsbHidKeyboard::SerialString)]={
  sizeof(OneButton::UsbHidKeyboard::SerialString),
  USB_DESC_TYPE_STRING,
  '1',0,'.',0,'0',0,'.',0,'0',0
};

const uint8_t OneButton::UsbHidKeyboard::ConfigurationString[sizeof(OneButton::UsbHidKeyboard::ConfigurationString)]={
  sizeof(OneButton::UsbHidKeyboard::ConfigurationString),
  USB_DESC_TYPE_STRING,
  'c',0,'f',0,'g',0
};

const uint8_t OneButton::UsbHidKeyboard::InterfaceString[sizeof(OneButton::UsbHidKeyboard::InterfaceString)]={
  sizeof(OneButton::UsbHidKeyboard::InterfaceString),
  USB_DESC_TYPE_STRING,
  'i',0,'t',0,'f',0
};

/*
 * Main entry point
 */

int main() {

  Nvic::initialise();

  // set up SysTick at 1ms resolution
  MillisecondTimer::initialise();

  OneButton onebutton;
  onebutton.run();

  // not reached
  return 0;
}

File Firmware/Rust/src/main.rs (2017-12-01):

#![feature(used)]
#![no_std]

extern crate cortex_m;
extern crate bluepill_usbhid;
extern crate onebutton;

//use onebutton::{GPIOB, RCC};
//use cortex_m::interrupt;
use bluepill_usbhid::*;

fn main() {
    hal_init();
    system_clock_config();

    usb_init();
    const MOMO: &str = "momo ";
    let mut hid_send_data: [u8; 128] = [0; 128];
    let mut hid_cmd_data: [u8; 128] = [0; 128];
    let mut hid_send_len: usize = 0;
    let mut hid_cmd_len: usize = 5;
    hid_cmd_data[..5].clone_from_slice(MOMO.as_bytes());
    loop {
        /* copy the received data from C buffer */
        unsafe {
            if hid_recv_len > 0 {
                let l = hid_recv_len as usize;
                hid_cmd_data[hid_cmd_len..hid_cmd_len+l]
                    .clone_from_slice(&hid_recv_data[..l]);
                hid_cmd_len += l;
                hid_recv_len = 0;
            }
        }

        if hid_cmd_len > 0 && hid_cmd_data[hid_cmd_len - 1] == b'\n'
        {
            hid_send_data[hid_send_len..hid_send_len+hid_cmd_len]
                .clone_from_slice(&hid_cmd_data[..hid_cmd_len]);
            hid_send_len += hid_cmd_len;
            hid_cmd_len = 5;
        }
        
        if hid_send_len > 0 {
            while !hid_send(&mut hid_send_data, hid_send_len) {
                hal_delay(100);
            }
            hid_send_len = 0;
        }
    }
}

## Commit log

2017-11-20 Initial Commit
    Initial Commit
    Includes: Schematic, Board (unrouted), and parts lib
    [CAPC-0603-T0.9-BN.stp, CAPC-1206-T1.8-BN.stp, CAPC-1210-T1.8-BN.stp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]
2017-11-26 Updated folder structure
    Updated folder structure, adding software next
    [CAPC-0603-T0.9-BN.stp, CAPC-1206-T1.8-BN.stp, CAPC-1210-T1.8-BN.stp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]
2017-11-26 Updated folder structure
    Updated folder structure
    [OneButton.GBL, OneButton.GBO, OneButton.GBS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]
2017-12-01 Rust codebase initial commit
    [CAPC-0603-T0.9-BN.stp, CAPC-1206-T1.8-BN.stp, CAPC-1210-T1.8-BN.stp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]
2017-12-01 Reconfigured the folder structure
    Reconfigured the folder structure
    [CAPC-0603-T0.9-BN.stp, CAPC-1206-T1.8-BN.stp, CAPC-1210-T1.8-BN.stp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]
2017-12-03 C Firmware - Hello World
    C Firmware - Hello World. TODO: Rewrite spi/uart libs, add USB lib
2017-12-19 CPP repo with working USB HID
    CPP repo with working USB HID, thanks Andy!
    [OneButton.brd, OneButton.sch]
2017-12-21 Working USB custom HID device
    Working USB custom HID device
2017-12-27 Copied UsbCustomHid to create UsbKeyboard
    UsbKeyboard.h is currently acting a custom hid device. In the following
    commits this file will be modified to act as a usb hid keyboard.
2018-01-01 Working single button press
    Remember to wait for the usb report to finish before sending the next
    one!
    [OneButton.brd, OneButton.sch]
2018-01-08 Working SPI DMA!
    Working SPI DMA. Next we need to implement an encoder for the WS8212
    (RGB -> SPI byte buffer).
2018-01-11 Working WS8212
    Wrote some janky code that drives 8 WS8212 LED’s. Next step is to clean
    it up and move it to a library.
2018-01-13 Fixed brightness bug
    Fixed brightness bug, bad for loop counter.
    [onebutton.cpp]
2018-01-14 Code commit before creating ws8212 libs and adding cad files
    Code commit before creating ws8212 libs and adding cad files
    [OneButton.brd, OneButton.sch, OneButtonCaseBottom.step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]
2018-01-19 Added debug instructions, removed build files
    Added debug instructions, removed build files
    [OneButton.sch, OneButtonCase_Top v10.stl]
2018-01-19 Removed Eagle CAD temp files
    Removed Eagle CAD temp files
2018-02-07 3D printed case update
    Updated 3D model. Button prints ESTOP when pressed.
    [OneButtonCase_Bottom v15.stl, OneButtonCase_Top v19.stl, OneButton_Reset_Boot_Button v7.stl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]
2018-02-09 Now launches firefox!
    Fun scripting starts here…
2018-02-11 Fun demo for spec.la
    Fun demo for spec.la. Next: clean up and reorganize code into libraries
    for easy scripting.
2018-02-17 SpecLA Star Wars Demo
    SpecLA Star Wars Demo
    [OneButton.brd]
2018-02-17 Dashboard and random colors
    Button now brings up dashboard and changes to a single random color.
2018-10-19 Mouse Wiggler
    Mouse wiggler for TVAC
    [Gourgen_Cube.stl]
2018-12-23 Added delay when connecting the device
    Added delay when connecting the device

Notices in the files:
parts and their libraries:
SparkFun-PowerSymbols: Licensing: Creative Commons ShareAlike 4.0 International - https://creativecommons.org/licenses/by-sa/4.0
